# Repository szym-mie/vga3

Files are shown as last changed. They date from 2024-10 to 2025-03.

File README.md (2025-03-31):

# VGA FPGA Video Card implementation

high level overview
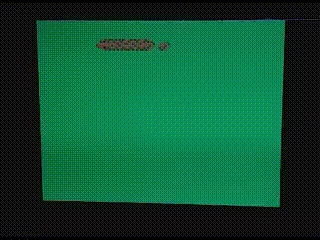
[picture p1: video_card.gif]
recording


## Display

This module works in standard VGA mode of 640x480 at 60Hz monitor refresh rate. The picture itself was scaled down to 160x120, but can be reverted to be true 640x480.

Full specification:

```
pixel clock: 25MHz
-0.7% deviation from ideal 25.175MHz

pixel mode: RGB222 6bpp
max analog color output voltage: 0.6V
sync signal level: 3.3V
```

## Hardware

### CAUTION

SPI connection requires 3.3V voltage level for safe operation

---

Apart from standard VGA connector, there is a SPI connection:

```
[  GND ]--(1)
< CSEL ]--(2)
< MOSI ]--(3)
< SCLK ]--(4)
```

FPGA:
```
MIMAS SPARTAN6 MODULE
```

Memory:
```
IS61LV5128AL 512K x 8 HIGH-SPEED CMOS STATIC RAM
access max time: 10, 12ns
full read/write max time: <20ns 
```

## Video memory

The video memory access is handled by module `vmmu.v`, which coordinates read access by VGA display unit and write access by SPI interface.

The basic working mechanism is the use of FIFOs to queue request addresses and read/write data.
Then the module can alternate between executing read and write requests, or if only one source has an active request, only that source is being processed.

The usage of FIFOs also make the system memory independent of other video circutry in terms of clock domains, further making the design more flexible.

## Schematics

As of recent update I've recovered KiCAD schematics and PCB design that contained system memory, SPI input and VGA connector. Those can be found under `kicad` directory.

main board schematic

## Modules

- spi.v - 8-bit SPI sampling receiver
- vbuf.v - video output buffer, also able to read 3 packed bytes to 4 pixels
- vcmd2v.v - video command processor, interacts with received data from SPI
- vctl.v - video output counter unit, sends signals related to video signal blanking and issues pixel read requests
- vsig.v - generates HSync and VSync VGA signals, along with global blank signal
- fifo.v - First-In-First-Out, asynchronous queue, with Full/Empty signals
- seqfifo.v - Generates sequences of addresses from staring address behaving as regular FIFO
- vmmu.v - video memory managment unit, time-slots reads and writes, controls memory chip
- vga.v - top-level module

## Bugs

#### 160x120 picture resolution (unresolved)

This was a hardware fault that prevented me from using a full 640x480. It turned out that one of the address lines was busted and it basically could corrupt the whole lower half of the screen. In theory I such issue could be remedied remap that region to an area that didn't use that address line.

#### PCB design mistake (fixed)

Due to confusing and just plain wrong schematic of pin headers that was published on Mimas site, one of data lines ended up connected to chip ground. This required an ad hoc jumper wire to be connected to a new location on a pin header, and a previous trace to be cut.

#### Dummy byte write needed after cursor move (unresolved)

An annoying issue, this results from tricky synchronization problems when the command to change cursor location is received. I was unable to fix it due to time constraint, instead a software workadround was devised, by writing a dummy byte just after `vga_set_xy`. This solution is not perfect and can cause flickering, depending on SPI data rate.

## Example driver code

A simple test driver code for ATMega88 (and its derivitives) can be found in `test_driver` directory. This test includes a simple color pallette pattern and animated analog speedometer.

The other example is included as a submodule [`vga_snake`](https://github.com/szym-mie/vga_snake) and it's a snake game demo written in C.

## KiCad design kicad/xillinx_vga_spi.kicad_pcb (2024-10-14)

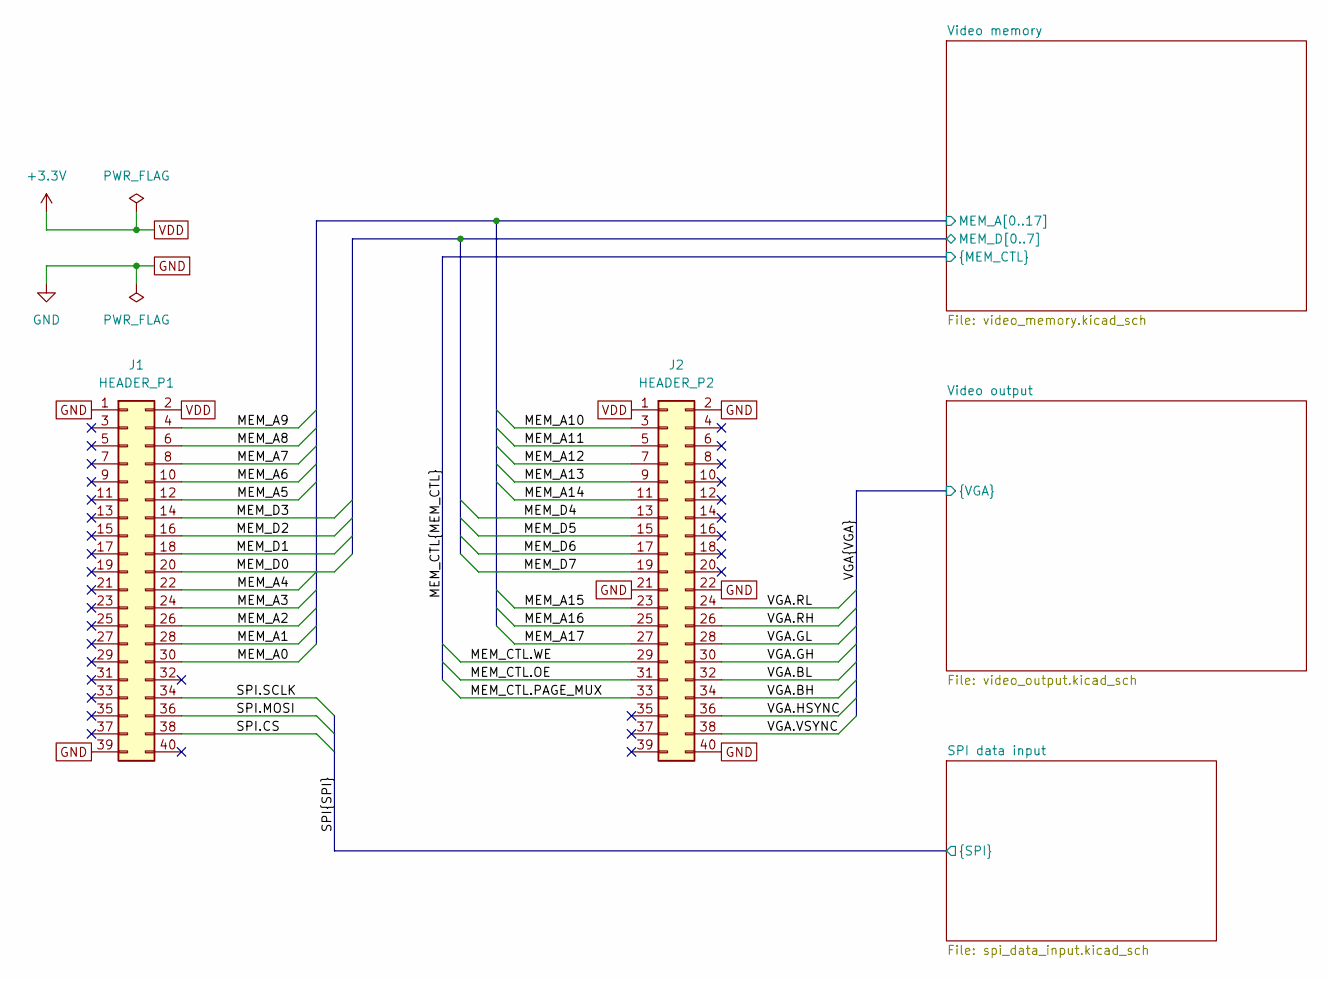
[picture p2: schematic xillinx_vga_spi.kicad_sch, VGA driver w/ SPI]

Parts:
J1: HEADER_P1; PinHeader_2x20_P2.54mm_Vertical
J2: HEADER_P2; PinHeader_2x20_P2.54mm_Vertical

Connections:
/MEM_CTL.OE: J2.31; also elsewhere on the board
/MEM_CTL.PAGE_MUX: J2.33; also elsewhere on the board
/MEM_CTL.WE: J2.29; also elsewhere on the board
/SPI.CS: J1.38; also elsewhere on the board
/SPI.MOSI: J1.36; also elsewhere on the board
/SPI.SCLK: J1.34; also elsewhere on the board
/VGA.BH: J2.34; also elsewhere on the board
/VGA.BL: J2.32; also elsewhere on the board
/VGA.GH: J2.30; also elsewhere on the board
/VGA.GL: J2.28; also elsewhere on the board
/VGA.HSYNC: J2.36; also elsewhere on the board
/VGA.RH: J2.26; also elsewhere on the board
/VGA.RL: J2.24; also elsewhere on the board
/VGA.VSYNC: J2.38; also elsewhere on the board
/Video memory/MEM_A0: J1.30; also elsewhere on the board
/Video memory/MEM_A1: J1.28; also elsewhere on the board
/Video memory/MEM_A2: J1.26; also elsewhere on the board
/Video memory/MEM_A3: J1.24; also elsewhere on the board
/Video memory/MEM_A4: J1.22; also elsewhere on the board
/Video memory/MEM_A5: J1.12; also elsewhere on the board
/Video memory/MEM_A6: J1.10; also elsewhere on the board
/Video memory/MEM_A7: J1.8; also elsewhere on the board
/Video memory/MEM_A8: J1.6; also elsewhere on the board
/Video memory/MEM_A9: J1.4; also elsewhere on the board
/Video memory/MEM_A10: J2.3; also elsewhere on the board
/Video memory/MEM_A11: J2.5; also elsewhere on the board
/Video memory/MEM_A12: J2.7; also elsewhere on the board
/Video memory/MEM_A13: J2.9; also elsewhere on the board
/Video memory/MEM_A14: J2.11; also elsewhere on the board
/Video memory/MEM_A15: J2.23; also elsewhere on the board
/Video memory/MEM_A16: J2.25; also elsewhere on the board
/Video memory/MEM_A17: J2.27; also elsewhere on the board
/Video memory/MEM_D0: J1.20; also elsewhere on the board
/Video memory/MEM_D1: J1.18; also elsewhere on the board
/Video memory/MEM_D2: J1.16; also elsewhere on the board
/Video memory/MEM_D3: J1.14; also elsewhere on the board
/Video memory/MEM_D4: J2.13; also elsewhere on the board
/Video memory/MEM_D5: J2.15; also elsewhere on the board
/Video memory/MEM_D6: J2.17; also elsewhere on the board
/Video memory/MEM_D7: J2.19; also elsewhere on the board
GND: J1.1, J1.39, J2.2, J2.21, J2.22, J2.40; also elsewhere on the board
VDD: J1.2, J2.1; also elsewhere on the board

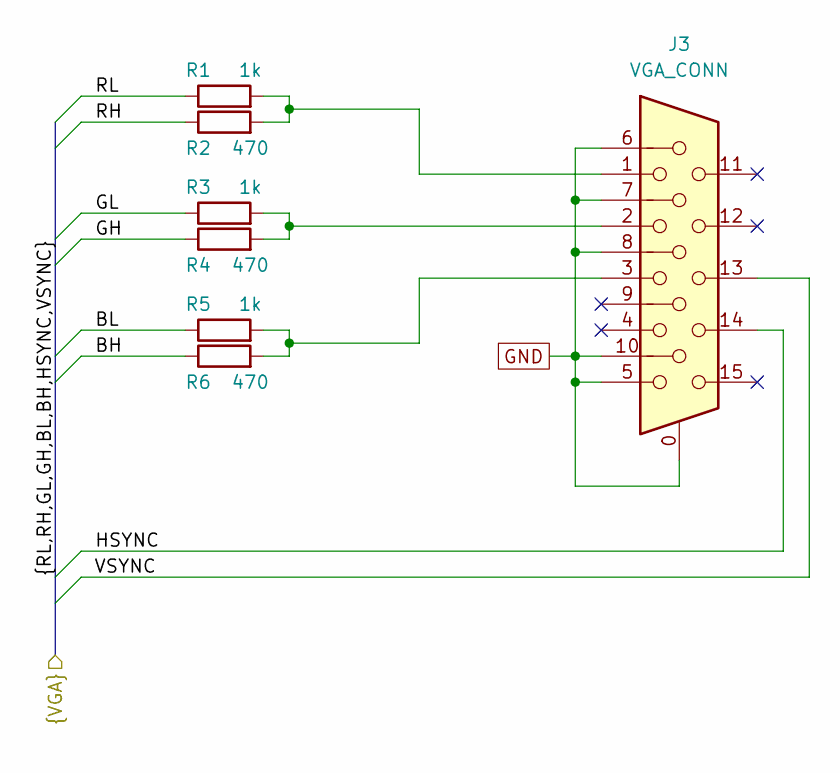
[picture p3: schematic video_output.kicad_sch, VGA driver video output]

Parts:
J3: VGA_CONN; L77HDE15SD1CH4FVGA
R1, R3, R5: 1k; R_0805_2012Metric_Pad1.20x1.40mm_HandSolder
R2, R4, R6: 470; R_0805_2012Metric_Pad1.20x1.40mm_HandSolder

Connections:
/VGA.BH: R6.1; also elsewhere on the board
/VGA.BL: R5.1; also elsewhere on the board
/VGA.GH: R4.1; also elsewhere on the board
/VGA.GL: R3.1; also elsewhere on the board
/VGA.HSYNC: J3.14; also elsewhere on the board
/VGA.RH: R2.1; also elsewhere on the board
/VGA.RL: R1.1; also elsewhere on the board
/VGA.VSYNC: J3.13; also elsewhere on the board
GND: J3.0, J3.5, J3.6, J3.7, J3.8, J3.10; also elsewhere on the board
unnamed: J3.1, R1.2, R2.2
unnamed: J3.2, R3.2, R4.2
unnamed: J3.3, R5.2, R6.2

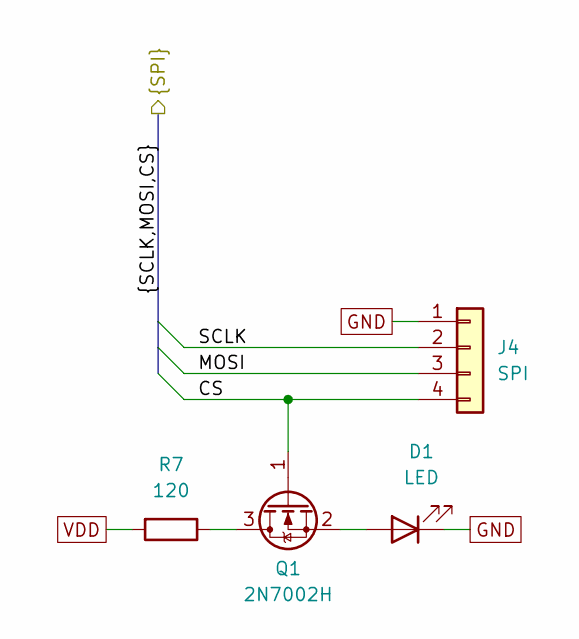
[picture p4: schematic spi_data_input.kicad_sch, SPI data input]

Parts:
D1: LED; LED_1206_3216Metric_Pad1.42x1.75mm_HandSolder
J4: SPI; PinSocket_1x04_P2.54mm_Horizontal
Q1: 2N7002H; SOT-23
R7: 120; R_0805_2012Metric_Pad1.20x1.40mm_HandSolder

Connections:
/SPI.CS: J4.4, Q1.1 (G); also elsewhere on the board
/SPI.MOSI: J4.3; also elsewhere on the board
/SPI.SCLK: J4.2; also elsewhere on the board
GND: D1.1 (K), J4.1; also elsewhere on the board
unnamed: D1.2 (A), Q1.2 (S)
unnamed: Q1.3 (D), R7.1
VDD: R7.2; also elsewhere on the board

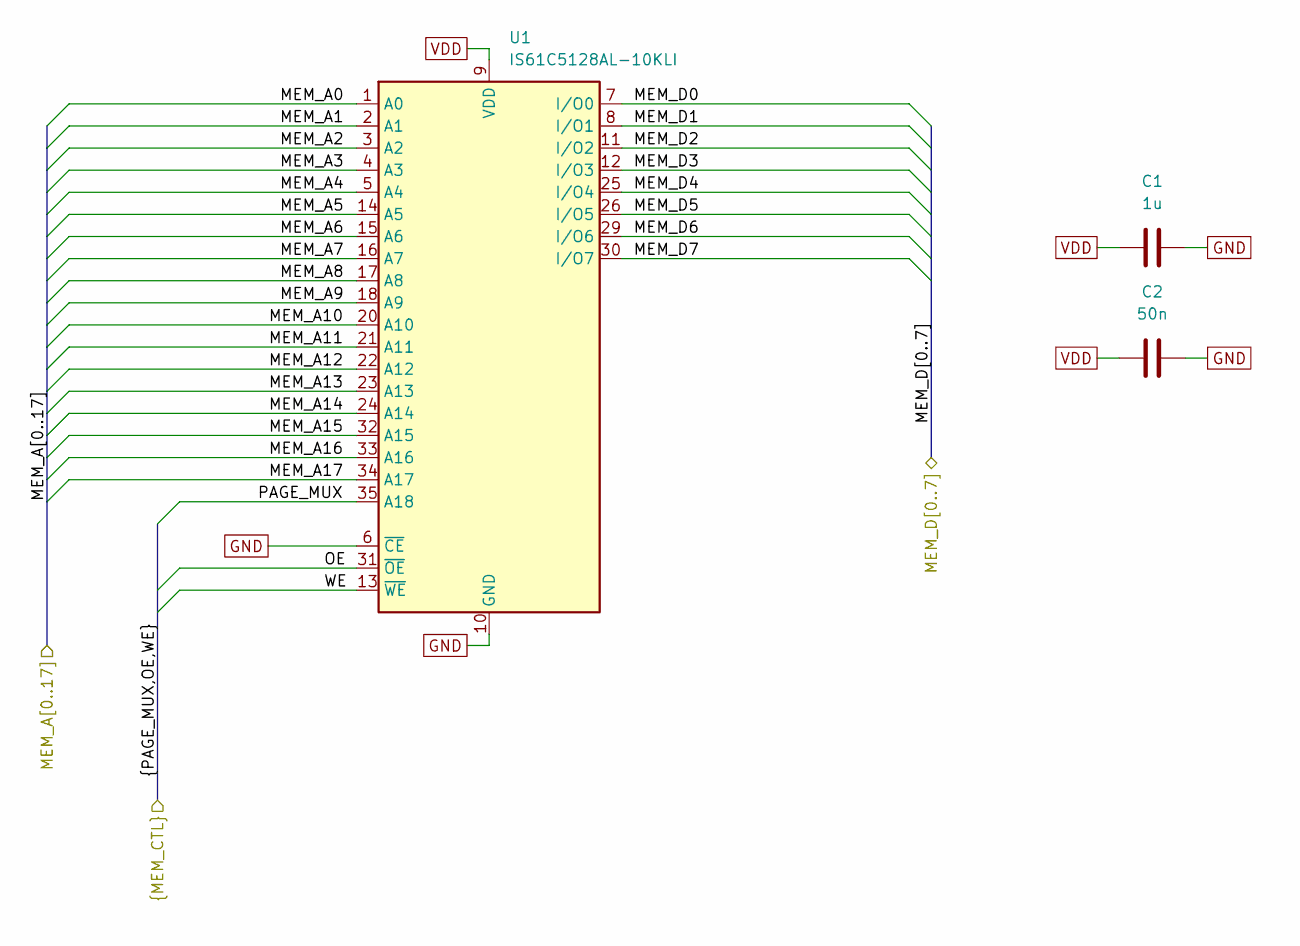
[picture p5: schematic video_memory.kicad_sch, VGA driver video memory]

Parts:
C1: 1u; C_0805_2012Metric_Pad1.18x1.45mm_HandSolder
C2: 50n; C_0805_2012Metric_Pad1.18x1.45mm_HandSolder
U1: IS61C5128AL-10KLI; SOJ-36_10.16x23.49mm_P1.27mm

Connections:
/MEM_CTL.OE: U1.31 (~OE); also elsewhere on the board
/MEM_CTL.PAGE_MUX: U1.35 (A18); also elsewhere on the board
/MEM_CTL.WE: U1.13 (~WE); also elsewhere on the board
/Video memory/MEM_A0: U1.1 (A0); also elsewhere on the board
/Video memory/MEM_A1: U1.2 (A1); also elsewhere on the board
/Video memory/MEM_A2: U1.3 (A2); also elsewhere on the board
/Video memory/MEM_A3: U1.4 (A3); also elsewhere on the board
/Video memory/MEM_A4: U1.5 (A4); also elsewhere on the board
/Video memory/MEM_A5: U1.14 (A5); also elsewhere on the board
/Video memory/MEM_A6: U1.15 (A6); also elsewhere on the board
/Video memory/MEM_A7: U1.16 (A7); also elsewhere on the board
/Video memory/MEM_A8: U1.17 (A8); also elsewhere on the board
/Video memory/MEM_A9: U1.18 (A9); also elsewhere on the board
/Video memory/MEM_A10: U1.20 (A10); also elsewhere on the board
/Video memory/MEM_A11: U1.21 (A11); also elsewhere on the board
/Video memory/MEM_A12: U1.22 (A12); also elsewhere on the board
/Video memory/MEM_A13: U1.23 (A13); also elsewhere on the board
/Video memory/MEM_A14: U1.24 (A14); also elsewhere on the board
/Video memory/MEM_A15: U1.32 (A15); also elsewhere on the board
/Video memory/MEM_A16: U1.33 (A16); also elsewhere on the board
/Video memory/MEM_A17: U1.34 (A17); also elsewhere on the board
/Video memory/MEM_D0: U1.7 (I/O0); also elsewhere on the board
/Video memory/MEM_D1: U1.8 (I/O1); also elsewhere on the board
/Video memory/MEM_D2: U1.11 (I/O2); also elsewhere on the board
/Video memory/MEM_D3: U1.12 (I/O3); also elsewhere on the board
/Video memory/MEM_D4: U1.25 (I/O4); also elsewhere on the board
/Video memory/MEM_D5: U1.26 (I/O5); also elsewhere on the board
/Video memory/MEM_D6: U1.29 (I/O6); also elsewhere on the board
/Video memory/MEM_D7: U1.30 (I/O7); also elsewhere on the board
GND: C1.2, C2.2, U1.6 (~CE), U1.10 (GND), U1.28 (GND); also elsewhere on the board
VDD: C1.1, C2.1, U1.9 (VDD), U1.27 (VDD); also elsewhere on the board

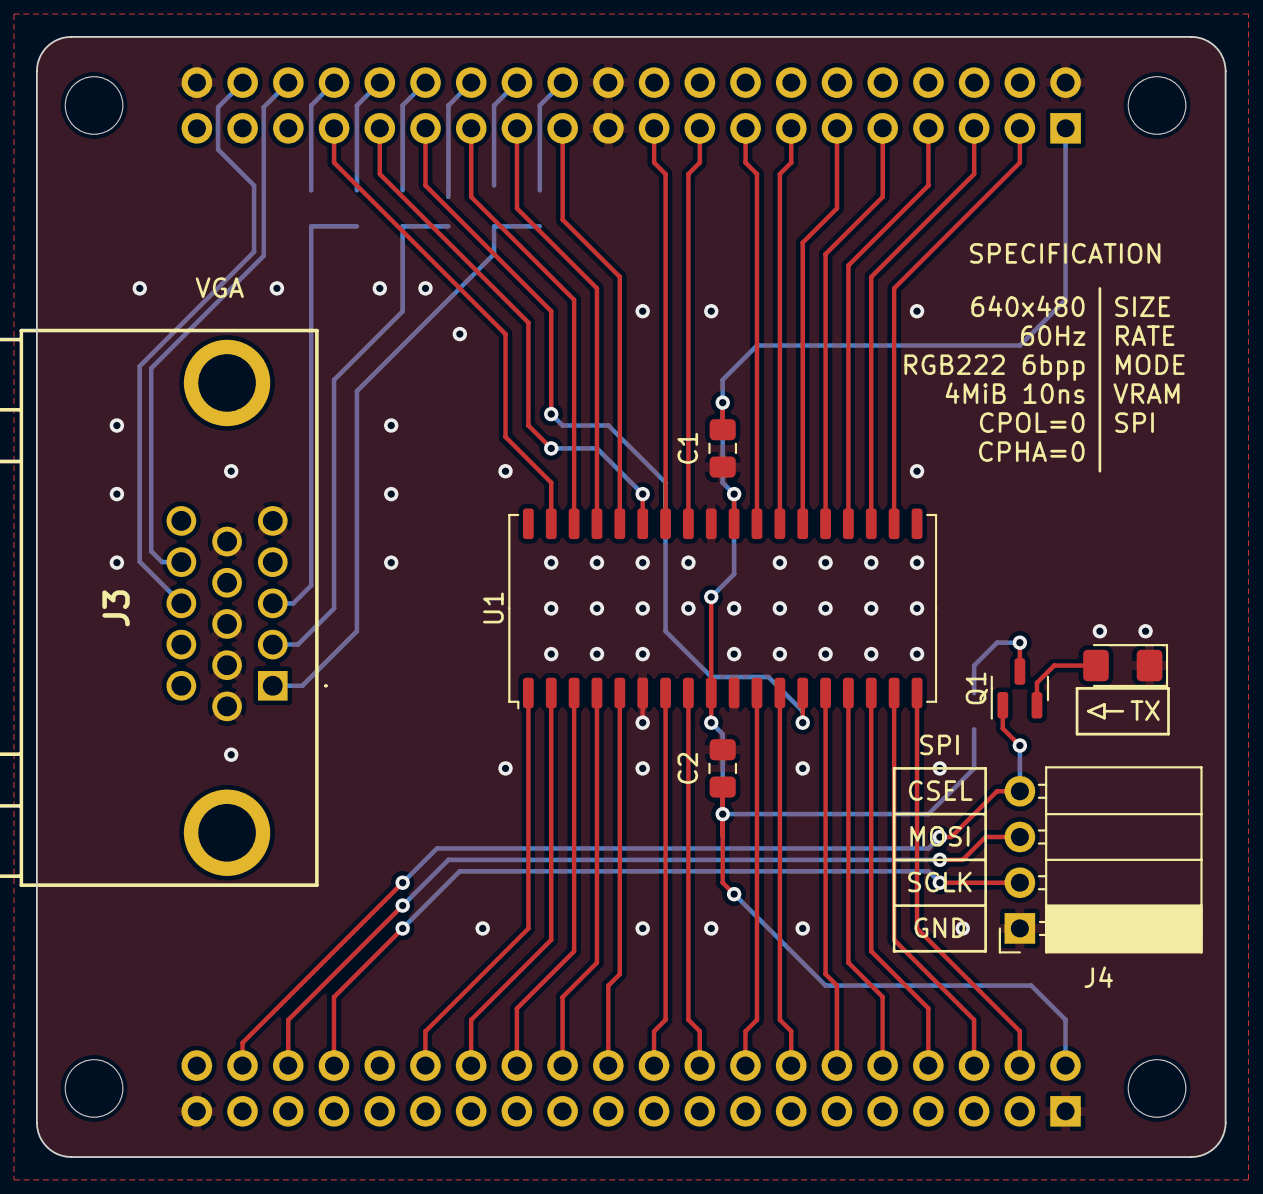
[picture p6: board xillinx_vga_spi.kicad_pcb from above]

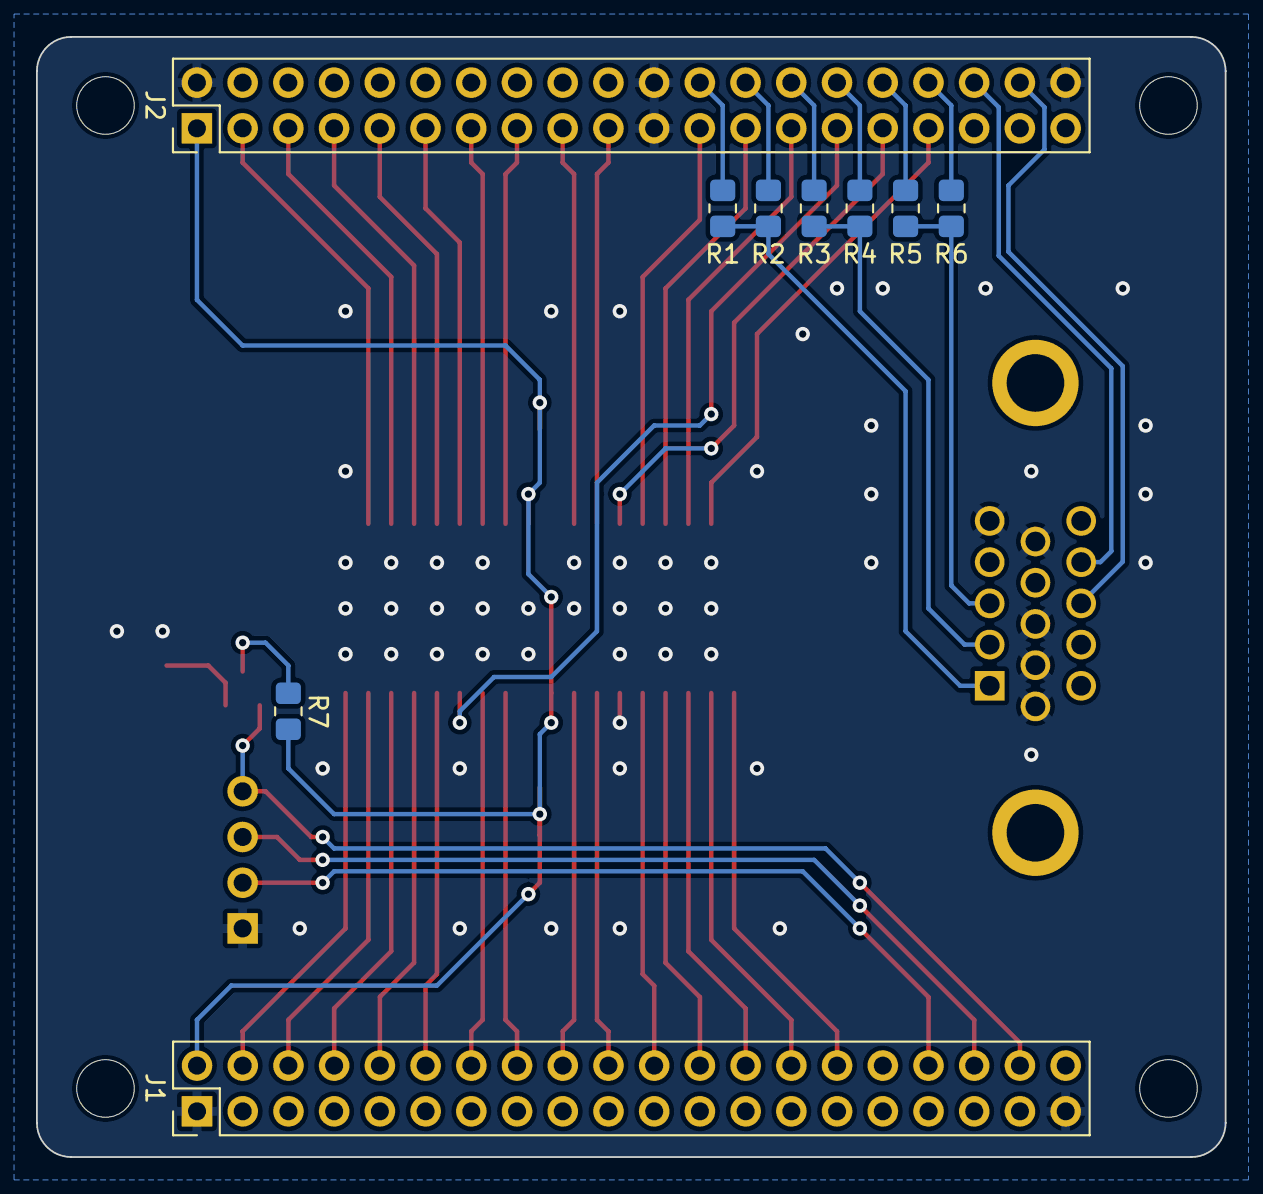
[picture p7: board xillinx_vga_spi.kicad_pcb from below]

Board: 2 copper layers, 66.0 x 62.2 mm, 16 parts (9 on the bottom side), 47 nets.

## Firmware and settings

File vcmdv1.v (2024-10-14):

`timescale 1ns/1ps

// Video Command receiver, write address generator - version 2
// C/D - command = 0, data = 1  on DataModeEnable

module vcmdv1 #(
    parameter AWIDTH = 18,
    parameter DWIDTH = 8
) (
    input wire ByteClkIn,
    input wire[DWIDTH-1:0] ByteIn,

    output reg DataClkOut,
    output wire[AWIDTH-1:0] AddrOut
);

localparam SWIDTH = 3;
localparam PGPARTSIZE = AWIDTH - 16;

// TODO finish vcmd data

localparam Noop = 8'h00;
localparam SetAddr = 8'h01;
localparam Write1P = 8'h10;

localparam ReadCmdId = 4'h0;
localparam WriteBytePacked = 4'h3;
localparam SetAddrPage = 4'h5;
localparam SetAddrHigh = 4'h6;
localparam SetAddrLow = 4'h7;

reg[AWIDTH-1:0] NextAddr = 1'b0;
reg[AWIDTH-1:0] ReadAddr = 1'b0;

reg[SWIDTH-1:0] State = 1'b0;

assign AddrOut = NextAddr;

always @(posedge ByteClkIn) begin
    DataClkOut <= 1'b0;
    case (State)
        ReadCmdId: begin
            case (ByteIn)
                Noop: State <= ReadCmdId;
                SetAddr: State <= SetAddrPage;
                Write1P: State <= WriteBytePacked;
            endcase
        end
        WriteBytePacked: begin
            DataClkOut <= 1'b1;
            NextAddr <= NextAddr + 1'b1;
        end
        SetAddrPage: begin
            ReadAddr[AWIDTH-1:16] <= ByteIn[PGPARTSIZE-1:0];
            State <= SetAddrHigh;
        end
        SetAddrHigh: begin
            ReadAddr[15:8] <= ByteIn;
            State <= SetAddrLow;
        end
        SetAddrLow: begin
            ReadAddr[7:0] <= ByteIn;
            NextAddr <= ReadAddr;		  
            State <= ReadCmdId;
        end
        default: State <= ReadCmdId;
    endcase
end

endmodule

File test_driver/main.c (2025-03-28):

#include "m88.h"
#include <stdint.h>

#define SPI_DDR DDRB
#define SPI_PORT PORTB
#define SCLK_PIN PINB5
#define MOSI_PIN PINB3
#define CSEL_PIN PINB2

void spi_init(void);
void spi_send(uint8_t byte);
void spi_send_buf(uint8_t *buf, uint16_t len);

void vga_set_xy(uint8_t x, uint8_t y);
void vga_write(uint8_t pixel);

uint8_t pttn[4] = { 0x0, 0x2, 0x1, 0x3 };

uint8_t tiles[12][8];

#define COL(C0, C1, C2, C3) ((C3<<6) | (C2<<4) | (C1<<2) | (C0<<0))

uint8_t font[60] = 
{
	COL(0, 1, 0, 0), COL(1, 0, 1, 0), COL(1, 0, 1, 0), COL(1, 0, 1, 0), COL(0, 1, 0, 0), COL(0, 0, 0, 0),
	COL(0, 1, 0, 0), COL(0, 1, 0, 0), COL(0, 1, 0, 0), COL(0, 1, 0, 0), COL(0, 1, 0, 0), COL(0, 0, 0, 0),
	COL(2, 1, 0, 0), COL(0, 0, 1, 0), COL(0, 1, 0, 0), COL(1, 0, 0, 0), COL(1, 1, 1, 0), COL(0, 0, 0, 0),
	COL(2, 1, 0, 0), COL(0, 0, 1, 0), COL(0, 1, 0, 0), COL(0, 0, 1, 0), COL(2, 1, 0, 0), COL(0, 0, 0, 0),
	COL(0, 1, 0, 0), COL(2, 1, 0, 0), COL(1, 0, 0, 0), COL(1, 1, 1, 0), COL(0, 1, 0, 0), COL(0, 0, 0, 0),
	COL(1, 1, 1, 0), COL(1, 0, 0, 0), COL(1, 1, 0, 0), COL(0, 0, 1, 0), COL(1, 1, 0, 0), COL(0, 0, 0, 0),
	COL(0, 1, 2, 0), COL(1, 0, 0, 0), COL(2, 1, 0, 0), COL(1, 0, 1, 0), COL(0, 1, 0, 0), COL(0, 0, 0, 0),
	COL(1, 1, 1, 0), COL(0, 0, 1, 0), COL(0, 2, 1, 0), COL(0, 1, 0, 0), COL(0, 1, 0, 0), COL(0, 0, 0, 0),
	COL(0, 1, 0, 0), COL(1, 0, 1, 0), COL(2, 1, 2, 0), COL(1, 0, 1, 0), COL(0, 1, 0, 0), COL(0, 0, 0, 0),
	COL(0, 1, 0, 0), COL(1, 0, 1, 0), COL(0, 1, 2, 0), COL(0, 0, 1, 0), COL(2, 1, 0, 0), COL(0, 0, 0, 0)
};

uint8_t lut[4] = { 0x00, 0x04, 0x08, 0x03 }; 

#define DIG(N, I) (((N)>>((I)<<2)) & 0xf)
#define DIG_LUT(N) ((N) > 5 ? (N) - 3 : (N))

void digit_write(uint8_t dig, uint8_t x, uint8_t y);

uint16_t to_bcd(uint16_t dec);

int
main(void)
{
	uint8_t col = 0;

	spi_init();

	for (uint8_t y = 0; y < 120; y++)
	{
		vga_set_xy(0, y);
		vga_write(0x00);

		for (uint8_t x = 0; x < 160; x++) vga_write(0x00);

		vga_write(0x00);
	}

	for (uint8_t row = 0; row < 4; row++)
	{
		for (uint8_t y = 0; y < 8; y++) 
		{
			vga_set_xy(4, 4 + y + row * 8);
			vga_write(0x00);

			for (uint8_t bar = 0; bar < 16; bar++)
			{
				uint8_t rc = (bar & 0x3)>>0;
				uint8_t gc = (bar & 0xc)>>2;
				col = (pttn[row]<<4) | (pttn[gc]<<2) | (pttn[rc]<<0);
				for (uint8_t x = 0; x < 8; x++) vga_write(col);
			}
			
			vga_write(0x00);
		}
	}

	

	for (uint8_t y = 0; y < 5; y++)
	{
		vga_set_xy(24, y + 58);
		vga_write(lut[0]);
		vga_write(lut[1]);

		for (uint8_t x = 0; x < 14 + y; x++)
		{
			vga_write(lut[y == 0]);
		}

		vga_write(lut[1]);
		vga_write(lut[2]);
	}

	for (uint8_t y = 0; y < 4; y++)
	{
		vga_set_xy(24, 66 - y);
		vga_write(lut[0]);
		vga_write(lut[1]);

		for (uint8_t x = 0; x < 14 + y; x++)
		{
			vga_write(lut[y == 0]);
		}

		vga_write(lut[1]);
		vga_write(lut[2]);
	}

	uint16_t hud_val = 60;
	uint16_t hud_val_bcd = to_bcd(hud_val);

	uint8_t cnt = 0;
	uint8_t accel = 1;

	// hud
	for (;;)
	{
		uint16_t hud_dig = hud_val_bcd;
		uint8_t x = 24;
		
		uint8_t last_dig = DIG_LUT((hud_dig & 0xf));
		uint8_t bar = 4 - (last_dig >= 5 ? last_dig - 5 : last_dig);
		for (uint8_t y = 41; y < 84; y++)
		{
			vga_set_xy(45, y);
			vga_write(0x00);

			for (uint8_t x = 0; x < 4; x++)
			{
				vga_write(lut[bar == 0]);
			}

			if (bar < 4) bar++;
			else bar = 0;

			vga_write(0x00);
		}

		uint8_t dig;
		uint8_t pad = 1;
		for (uint8_t i = 0; i < 3; i++) 
		{
			x += 4;
			hud_dig <<= 4;
			dig = DIG_LUT((hud_dig & 0xf000) >> 12);
			if (pad && dig > 0) pad = 0;
			if (!pad) digit_write(dig, x, 60);
		}

		if (cnt == 0)
		{
			hud_val += accel;
			hud_val_bcd = to_bcd(hud_val);
		}

		// hud test code
		if (hud_val >= 85 && hud_val < 120) accel = 2;
		if (hud_val >= 120 && hud_val < 432) accel = 3;
		if (hud_val >= 432 && hud_val < 476) accel = 2;
		if (hud_val >= 476 && hud_val < 511) accel = 1;
		if (hud_val >= 511) accel = 0;

		cnt = (cnt + 1) & 0x3;
	}

	return 0;
}

void
spi_init(void)
{
	SPI_DDR = MOSI_PIN | SCLK_PIN | CSEL_PIN;
	SPI_PORT |= CSEL_PIN;
	SPCR = SPE | MSTR | SPR0;
}

void
spi_send(uint8_t byte)
{
	SPI_PORT &= ~CSEL_PIN;
	SPDR = byte;
	while (!(SPSR & SPIF));
	SPI_PORT |= CSEL_PIN;
}

void
spi_send_buf(uint8_t *buf, uint16_t len)
{
	uint8_t *buf_end = buf + len;
	uint8_t *byte;
	for (byte = buf; byte < buf_end; byte++)
		spi_send(*byte);
}

void 
vga_set_xy(uint8_t x, uint8_t y)
{
	spi_send(0x11);
	spi_send(x);
	spi_send(y);
}

void 
vga_write(uint8_t pixel)
{
	spi_send(0x20);
	spi_send(pixel);
}

void 
digit_write(uint8_t dig, uint8_t x, uint8_t y)
{
	uint8_t offset = (dig<<2) + (dig<<1);
	uint8_t *dig_pix = font + offset;
	for (uint8_t row = 0; row < 6; row++)
	{
		vga_set_xy(x, y + row);
		vga_write(0x00);
		
		uint8_t row_pix = *(dig_pix + row);
		uint8_t pix;

		for (uint8_t col = 0; col < 3; col++)
		{
			pix = (row_pix & 0x3);
			row_pix >>= 2;
			vga_write(lut[pix]);
		}
	}
}

uint16_t
to_bcd(uint16_t dec)
{
	uint16_t bcd = 0;
		
	uint16_t dec_mask = 0x8000;
	
	for (uint8_t i = 0; i < 16; i++)
	{
		bcd <<= 1;
		if (dec & dec_mask) bcd |= 0x1;
		dec <<= 1;

		uint8_t bcd_mask = 0xf;
		uint8_t bcd_thrs = 0x4;
		uint8_t bcd_add = 0x3;
		for (uint8_t j = 0; j < 4; j++)
		{
			if ((bcd & bcd_mask) > bcd_thrs) bcd += bcd_add;
			bcd_mask <<= 4;
			bcd_thrs <<= 4;
			bcd_add <<= 4;
		}
	}

	return bcd;
}

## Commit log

2024-10-14 Upload schematics, late noon README
    [analog_unit.kicad_sch, selectors.kicad_sch, spi_data_input.kicad_sch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]
2024-10-14 Late afternoon driver code upload and README update
